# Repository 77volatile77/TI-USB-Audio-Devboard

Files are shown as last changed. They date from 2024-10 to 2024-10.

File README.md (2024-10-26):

# TI-USB-Audio-Devboard



A breadboard adapter for the PCM2906C: A USB 1.1 audio codec made by Texas Instruments. Note: the way the header pinout is defined, this board is only intended to be used *as a DAC.* However, you can choose to DNP the pull-down resistors on the VINR + VINL pins and solder jumpers onto the pad and use it that way.

# Demo
https://www.youtube.com/watch?v=z2hdiVDINO0

# Viewing source

You can either clone the project and view it on your copy of KiCad, or you can use [KiCanvas](https://kicanvas.org/) to look at the schematics on the web.

Enter the following URL onto KiCanvas: https://github.com/77volatile77/TI-USB-Audio-Devboard/tree/main/dac

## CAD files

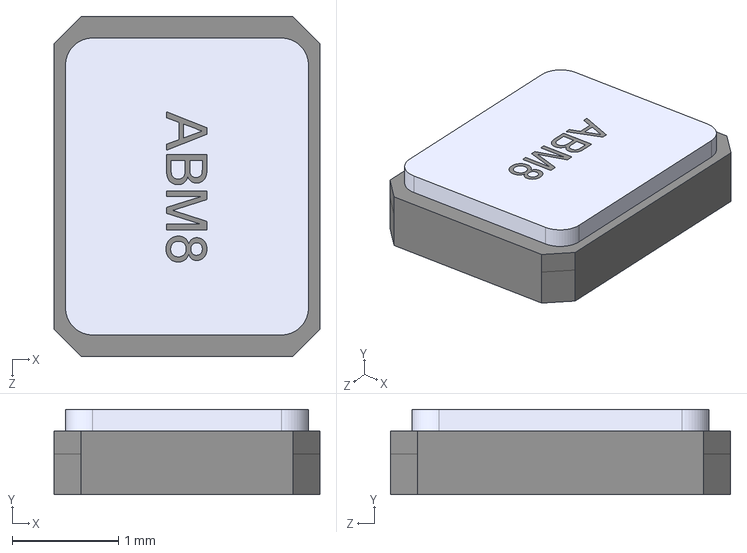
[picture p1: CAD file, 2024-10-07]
dac/components/ABM8_12_000MHZ_12_B1U_T/ABM8-12.000MHZ-12-B1U-T.step
2.50 x 0.8 x 3.20 mm

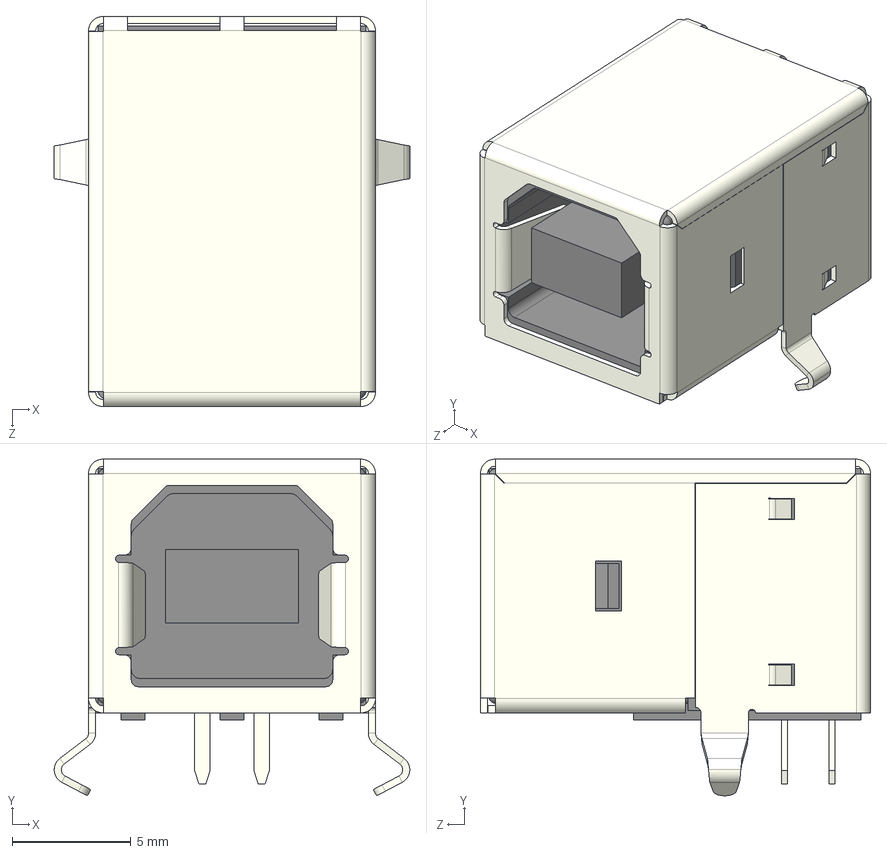
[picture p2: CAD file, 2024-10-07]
dac/components/Same_Sky_UJ2-BH-1-TH/Same_Sky_UJ2-BH-1-TH.step
15.0 x 14.2 x 16.5 mm

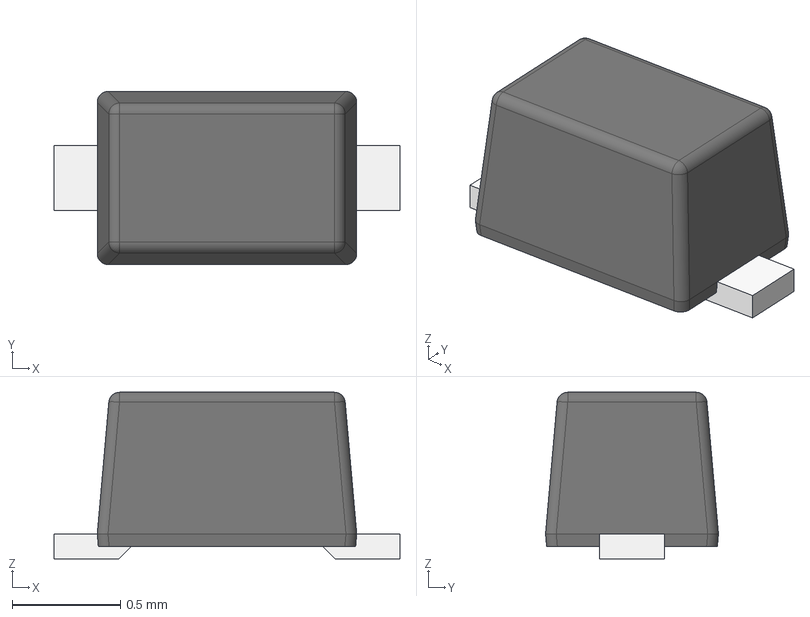
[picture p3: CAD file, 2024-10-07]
dac/components/ul_ESD321DYAR/KiCADv6/DYA0002A.stp
1.60 x 0.8 x 0.77 mm
FRAME-DYA0002A
BODY-SOT
PIN1-ID

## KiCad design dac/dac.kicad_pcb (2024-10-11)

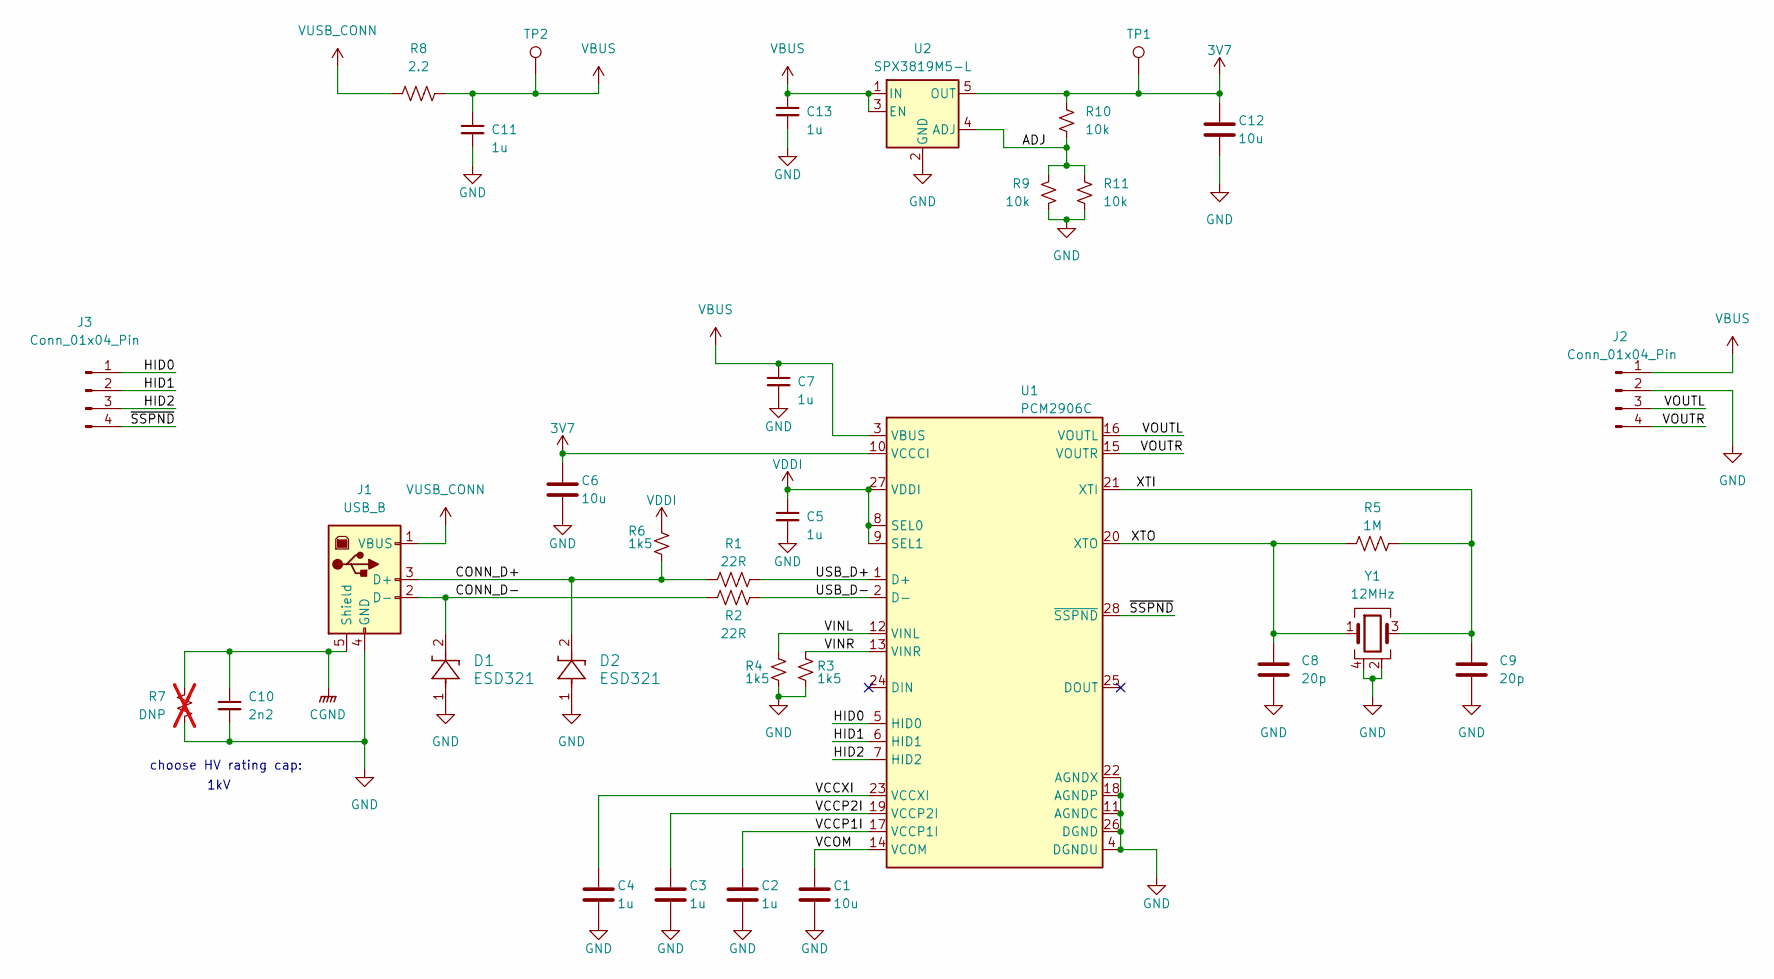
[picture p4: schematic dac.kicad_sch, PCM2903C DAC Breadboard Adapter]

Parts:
C1, C6, C12: 10u; C_0805_2012Metric_Pad1.18x1.45mm_HandSolder
C2, C3, C4, C5, C7, C11, C13: 1u; C_0402_1005Metric_Pad0.74x0.62mm_HandSolder
C8, C9: 20p; C_0402_1005Metric_Pad0.74x0.62mm_HandSolder
C10: 2n2; C_0805_2012Metric_Pad1.18x1.45mm_HandSolder
D1, D2: ESD321; SOT5x3_DYA_TEX-M
J1: USB_B; USB_B_OST_USB-B1HSxx_Horizontal
J2, J3: Conn_01x04_Pin; PinHeader_1x04_P2.54mm_Vertical
R1, R2: 22R; R_0402_1005Metric_Pad0.72x0.64mm_HandSolder
R3, R4, R6: 1k5; R_0402_1005Metric_Pad0.72x0.64mm_HandSolder
R5: 1M; R_0402_1005Metric_Pad0.72x0.64mm_HandSolder
R7: DNP; R_0402_1005Metric_Pad0.72x0.64mm_HandSolder; not fitted
R8: 2.2; R_0603_1608Metric_Pad0.98x0.95mm_HandSolder
R9, R10, R11: 10k; R_0402_1005Metric_Pad0.72x0.64mm_HandSolder
TP1, TP2: TestPoint; TestPoint_Pad_D1.0mm
U1: PCM2906C; SSOP-28_5.3x10.2mm_P0.65mm
U2: SPX3819M5-L; SOT-23-5
Y1: 12MHz; XTAL_ABM8-12.000MHZ-12-B1U-T

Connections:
3V7: C6.1, C12.1, R10.1, TP1.1, U1.10 (VCCCI), U2.5 (OUT)
/ADJ: R9.1, R10.2, R11.1, U2.4 (ADJ)
/CONN_D+: D2.2, J1.3 (D+), R1.1, R6.2
/CONN_D-: D1.2, J1.2 (D-), R2.1
/HID0: J3.1, U1.5 (HID0)
/HID1: J3.2, U1.6 (HID1)
/HID2: J3.3, U1.7 (HID2)
/USB_D+: R1.2, U1.1 (D+)
/USB_D-: R2.2, U1.2 (D-)
/VCCP1I: C2.1, U1.17 (VCCP1I)
/VCCP2I: C3.1, U1.19 (VCCP2I)
/VCCXI: C4.1, U1.23 (VCCXI)
/VCOM: C1.1, U1.14 (VCOM)
/VINL: R4.1, U1.12 (VINL)
/VINR: R3.1, U1.13 (VINR)
/VOUTL: J2.3, U1.16 (VOUTL)
/VOUTR: J2.4, U1.15 (VOUTR)
/XTI: C9.1, R5.2, U1.21 (XTI), Y1.3
/XTO: C8.1, R5.1, U1.20 (XTO), Y1.1
/~SSPND: J3.4, U1.28 (~SSPND)
CGND: C10.1, J1.5 (Shield), R7.1
GND: C1.2, C2.2, C3.2, C4.2, C5.2, C6.2, C7.2, C8.2, C9.2, C10.2, C11.2, C12.2, C13.2, D1.1, D2.1, J1.4 (GND), J2.2, R3.2, R4.2, R7.2, R9.2, R11.2, U1.4 (DGNDU), U1.11 (AGNDC), U1.18 (AGNDP), U1.22 (AGNDX), U1.26 (DGND), U2.2 (GND), Y1.2, Y1.4
VBUS: C7.1, C11.1, C13.1, J2.1, R8.2, TP2.1, U1.3 (VBUS), U2.1 (IN), U2.3 (EN)
VDDI: C5.1, R6.1, U1.8 (SEL0), U1.9 (SEL1), U1.27 (VDDI)
VUSB_CONN: J1.1 (VBUS), R8.1

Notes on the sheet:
choose HV rating cap:
1kV

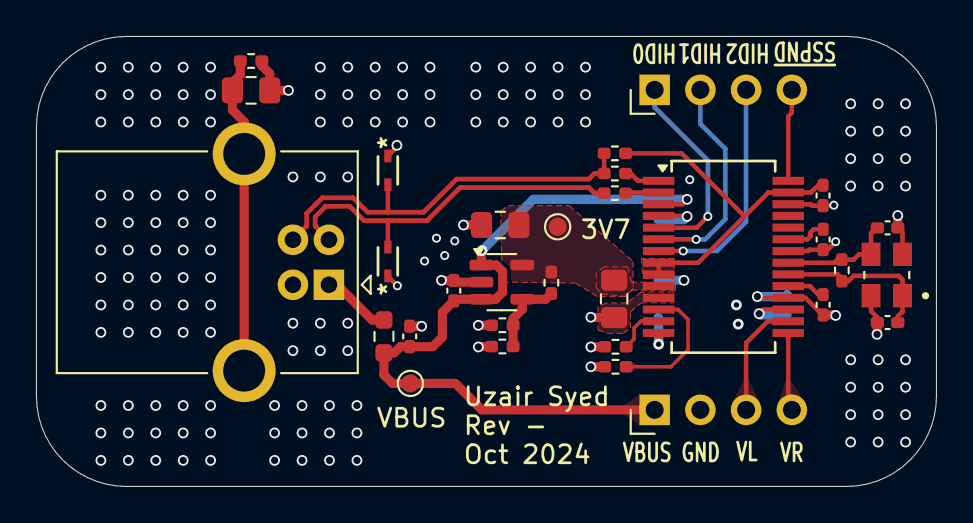
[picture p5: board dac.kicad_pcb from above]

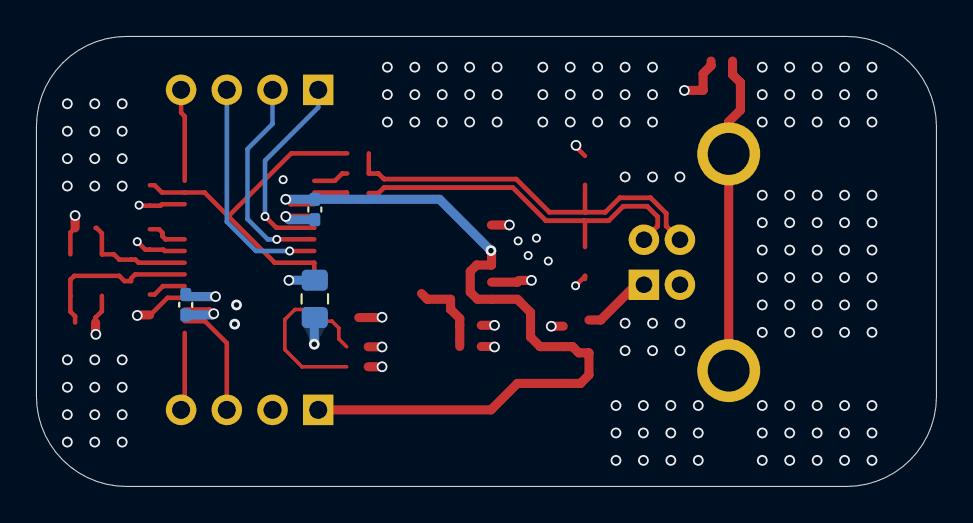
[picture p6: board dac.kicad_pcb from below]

Board: 4 copper layers, 50.0 x 25.0 mm, 34 parts (3 on the bottom side), 25 nets.

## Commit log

2024-10-07 finished component placement, need to figure out header pinouts
    [ABM8-12.000MHZ-12-B1U-T.step, Same_Sky_UJ2-BH-1-TH.step, dac.kicad_pcb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]
2024-10-07 added 3D bodies for ESD diodes
    [DYA0002A.stp, dac.kicad_pcb]
2024-10-07 changed README to reflect the fact that you can still use the ADC part of the codec.
2024-10-07 started layout
    [dac.kicad_pcb]
2024-10-08 layout is complete
    [dac.kicad_pcb, dac.kicad_sch]
2024-10-08 added stitching, redid 3d models
    [dac.kicad_pcb]
2024-10-08 added teardrops & extra stitching
    [dac.kicad_pcb]
2024-10-09 labeled headers and test points
    [dac.kicad_pcb]
2024-10-10 final cleanup
    [dac.kicad_pcb, dac.kicad_sch]
2024-10-10 add output files
    [dac-B_Cu.gbl, dac-B_Mask.gbs, dac-B_Paste.gbp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]
2024-10-11 changed U1 name to correct chip PCM2906C
    [dac.kicad_pcb, dac.kicad_sch]
